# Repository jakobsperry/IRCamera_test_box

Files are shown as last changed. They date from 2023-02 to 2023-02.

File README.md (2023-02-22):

# How to use

Connect the IR camera wires in order top to bottom:

<p>
  Black<br>
  Green<br>
  Yellow<br>
  Red<br>
</p>

<p>
  Point the camera at the LED's and you should see a red light on the IR camera and circles on the OLED showing the location of the LED's with respect to the cameras field of view
  </p>
  
<p align="center">
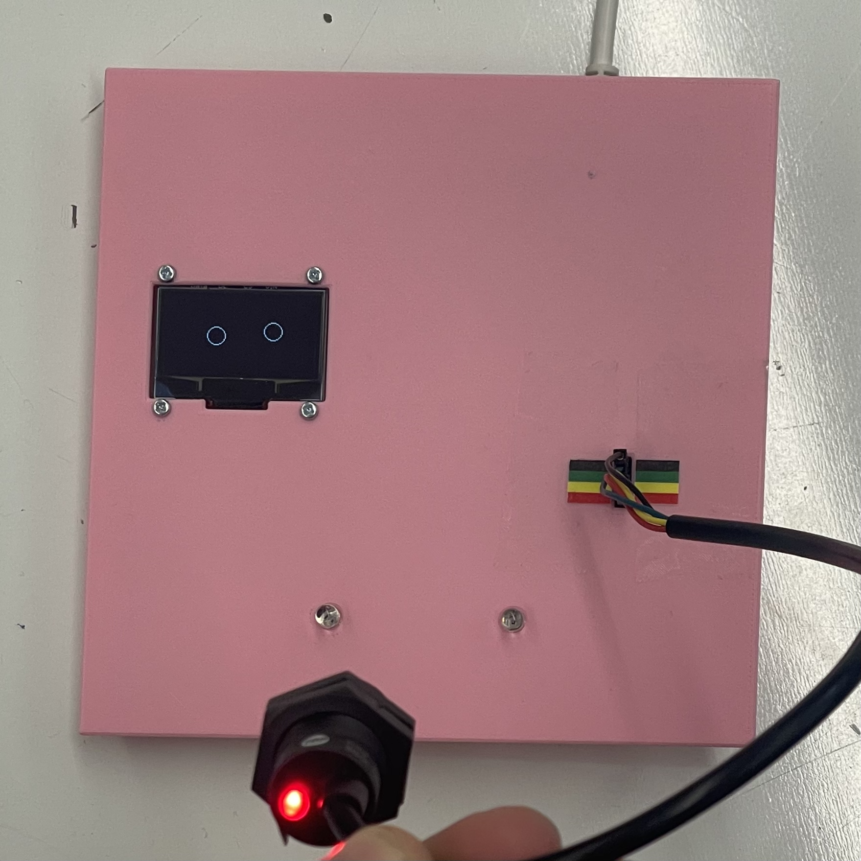
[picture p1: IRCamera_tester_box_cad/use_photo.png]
using boxp
  
</p>

# Wiring

<p>
  <b>Components:</b><br>
  1x STEMA QT 128x64 OLED display (https://www.adafruit.com/product/326)<br>
  1x ESP23_devkitc_v4 <br>
  2x 5mm IR LED<br>
</p>

<p align="center">
  Box wiring
</p>

<p>
  <b>Wiring:</b><br>
  OLED vin -> ESP 5V<br>
  OLED gnd -> ESP gnd<br>
  OLED rst -> ESP 23<br>
  OLED clk -> ESP 22<br>
  OLED data -> ESP 21<br>
  
  LED+ -> 330 ohm -> ESP 5V<br>
  LED- -> ESP gnd<br>

</p>

# CAD and Assembly
<p>
  <b>Components:</b> <br>
  1x 3D printed box (CAD avalible in repo) <br>
  4x 2-56 0.25" Pan head bolt <br>
  4x 2-26 nut <br>
  10x M3 Heat inset nut <br>
  10x M3 6mm socket head cap screw <br>
</p>

<p>
  <b> Assembly:</b><br>
  1) Insert all heat insert nuts into box top. There are 2 inserts per side and 2 inserts to mount the ESP32<br>
  2) Screw the SDoldered prototyping board and the OLED display to the printed box top. Use M3 screws for the board and 2-56 for the OLED <br>
  3) Print the pinout colors PDF and tape it to the box to indicate the correct IR Camera wiring<br>
</p>
<p align="center">
  Box Top<br>
  heat insert
</p>

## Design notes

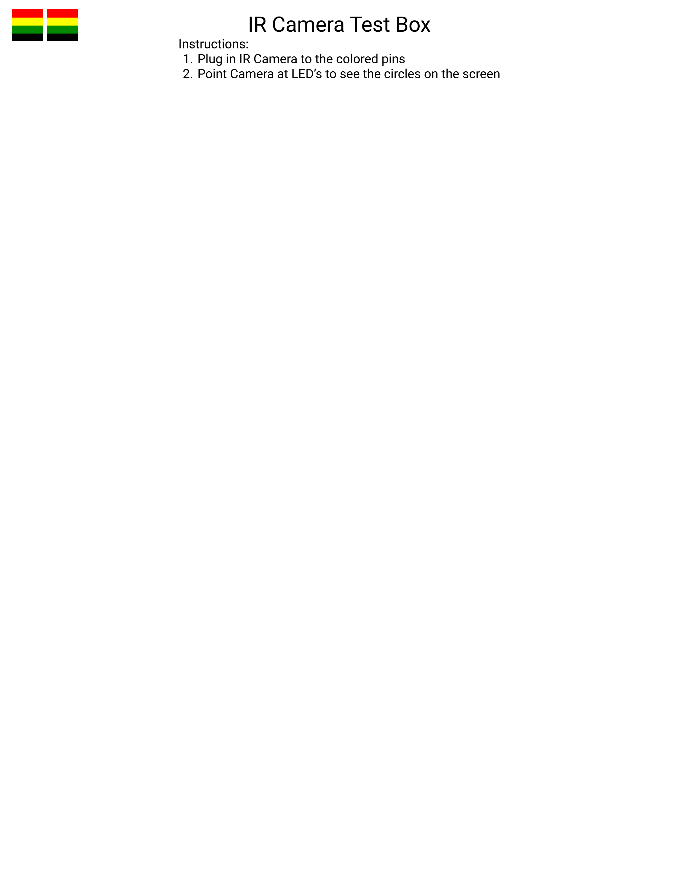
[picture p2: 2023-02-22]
IRCamera_tester_box_cad/pinout_colors.png

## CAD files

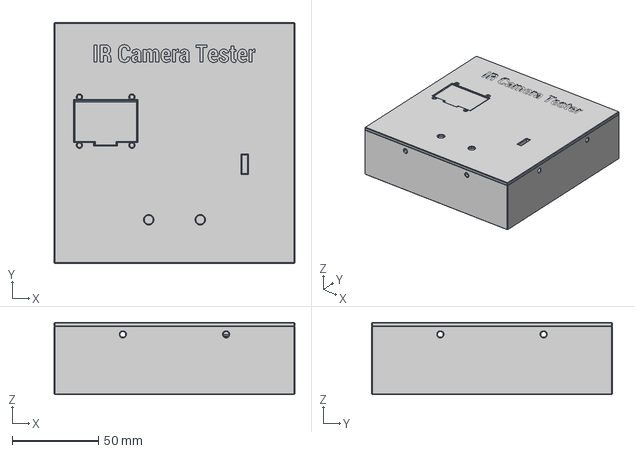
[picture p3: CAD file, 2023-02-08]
IRCamera_tester_box_cad/IR_camera_test_box.step
140.0 x 140.0 x 42.0 mm
OLED Display

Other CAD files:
IRCamera_tester_box_cad/IR camera test box.f3z
IRCamera_tester_box_cad/IR camera test box.step

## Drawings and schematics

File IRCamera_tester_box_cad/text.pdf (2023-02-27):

## IR Camera Test Box

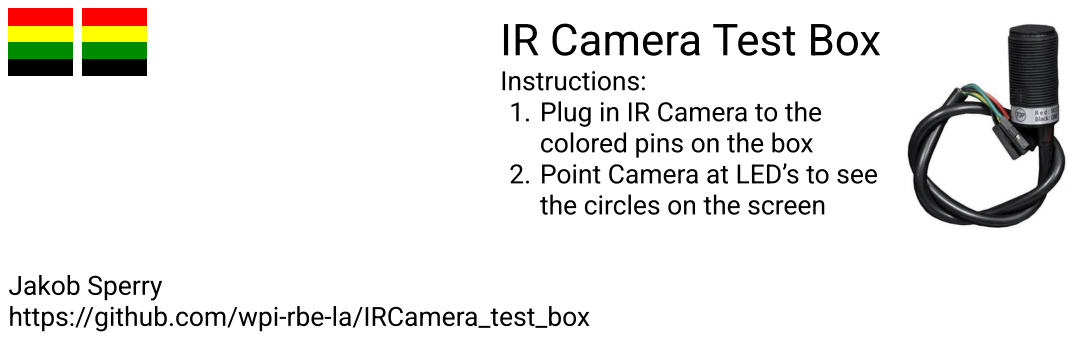
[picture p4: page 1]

Instructions'
$ Plug in IR Camera to the
colored pins on the bo
$ Point Camera at LED’s to see
the circles on the screen

Jakob Sperry
https://github.com/wpi-rbe-la/IRCamera_test_box

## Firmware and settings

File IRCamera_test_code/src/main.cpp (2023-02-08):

#include "IRcamera.h"
#include "Display.h"

IRcamera irCamera;
Display disp;


void setup() {
  irCamera.init();
  disp.init();
}

void loop() {
  irCamera.update();
  disp.clear();
  for (int i = 0; i < 4; i++){
    if(irCamera.getX(i) != 1023 && irCamera.getY(i) != 1023){
      disp.sendPoint(irCamera.getX(i), irCamera.getY(i));
    }
  }
  disp.update();
  irCamera.print();

}

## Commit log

2023-02-08 updated CAD and readme
    [IR camera test box.step]
2023-02-08 updated CAD
    [IR camera test box.f3z, IR_camera_test_box.step]
2023-02-22 updated pinout print sheet
